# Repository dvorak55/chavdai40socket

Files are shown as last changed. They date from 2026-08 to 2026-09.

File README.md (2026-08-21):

# Chavdai40% Socket のご紹介
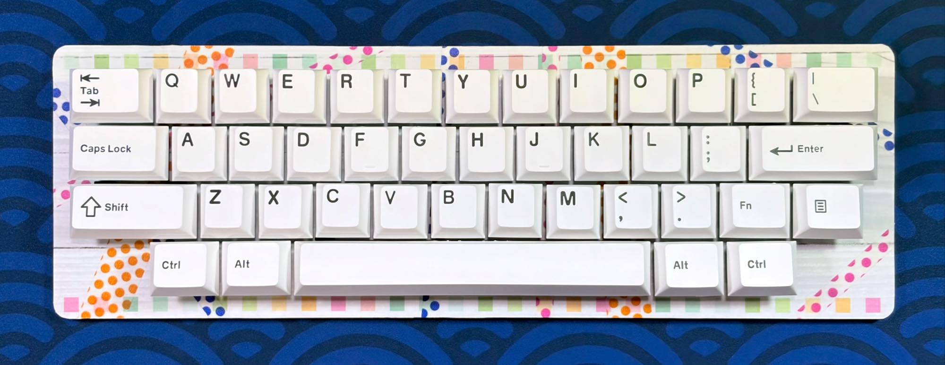
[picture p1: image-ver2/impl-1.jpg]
chavdai

 - Chavdai40%は、ちゃぶだいよんじゅっぱーせんと、と読みます
 - 古き良きちゃぶ台をイメージしました

### ロゴ
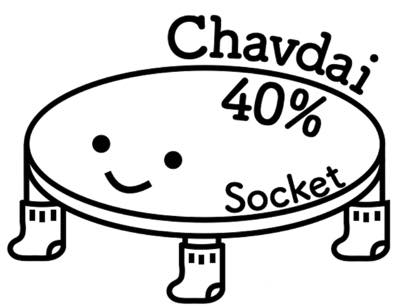
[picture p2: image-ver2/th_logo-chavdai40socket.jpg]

### 基板写真
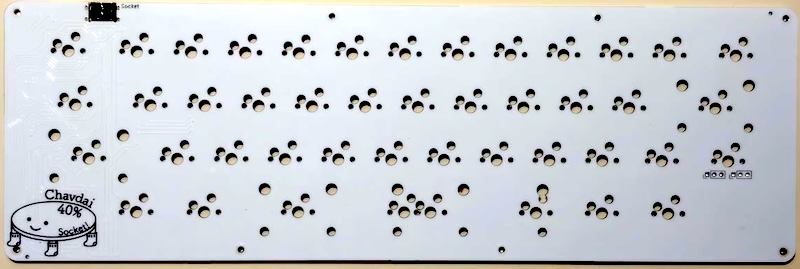
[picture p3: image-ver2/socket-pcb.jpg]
socket-pcb


## ★★★　詳細な組み立て説明はキットに同梱の説明書に記載しておりますので省略しますが、この場所では写真が掲載可能なので、デコレーション例や、組み立てで難しそうな点をご紹介いたします　★★★

## Chavdai40% Socket（ソケット）の特徴
 - デコレーションできる、コンパクトで健気なキーボード
    - 40％キーボードというサイズ感（キー数44、または42）
    - ソケット対応なので、とりあえず組み立てて後でデコレーションするのも可能です
    - キーボードケースが付属しているので、持ち運びしやすいです
 - リーズナブルなキーキャップが選べます
    - Amazonでも売っているキーキャップが使えます
    - ちょっと高価なキーキャップも、もちろん使えます
    - 日本語キーボードの縦長Enterキーは使えません
 - Vial（ヴァイアル）というソフトに対応しています
    - 40％キーボードでも数字と記号が入力できます
    - Ctrl＋a等の組み合わせを1つのキーに登録することも可能です
 - USB-Cでパソコン／スマホ／タブレットと接続して使えます

## Chavdai40%の組み立て例
### 組立例１（Chavdai40% Socket ＋ ダイソー リメイクシート ナチュラルウッド ホワイト ＋ mtマスキングテープ ドットシリーズ（オレンジ、ピンク、青） ＋ mtマスキングテープ幅3ｍｍシリーズ ＋ ダイソー マスキングテープ ＋ ダイソー デコレーションシール ＋ 一般的な白地に黒文字のキーキャップ）
なるべくリーズナブルにおしゃれなデザインを目標に、ダイソーの白い木目のリメイクシートを下地に、パステル調のマスキングテープでデコレーションしてみました。キーキャップは同じくリーズナブルに入手できる白地に黒文字のキーキャップを取り付けて、シンプルながらも明るい印象に仕上げました。  
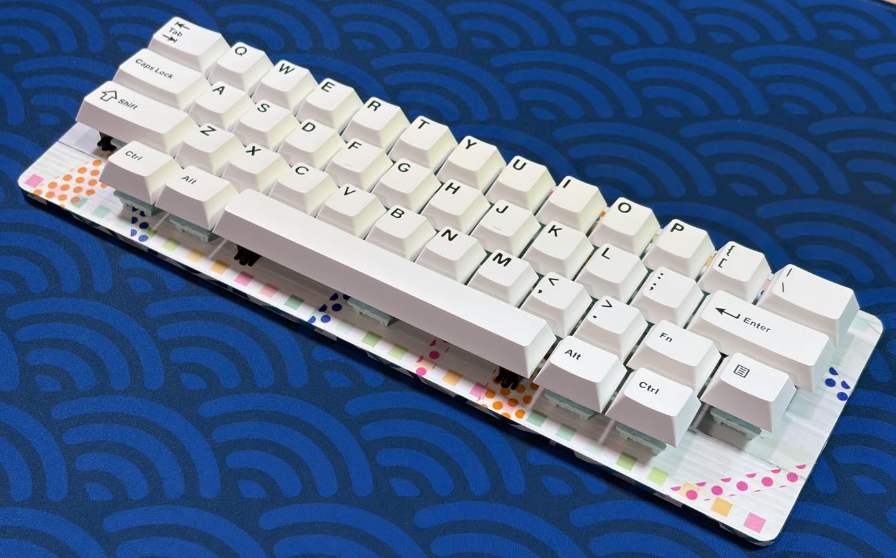
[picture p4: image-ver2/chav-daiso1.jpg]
chav-daiso1

マスキングテープをランダムに配置して、おしゃれな感じにしてみました。  
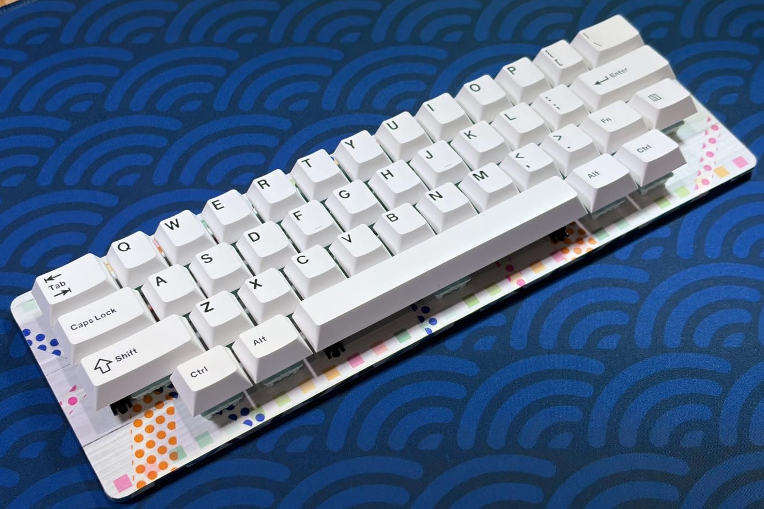
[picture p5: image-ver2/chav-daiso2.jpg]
chav-daiso2

リメイクシートとキーキャップセットは以下で購入可能です（2026年8月15日現在）  

●リメイクシート（ダイソー）  
[https://jp.daisonet.com/products/4900662759840)](https://jp.daisonet.com/products/4900662759840)  
●マスキングテープ（mtドット系）  
[https://shop.masking-tape.jp/products/list.php?category=99](https://shop.masking-tape.jp/products/list.php?category=99)  
●キーキャップ（Amazon.co.jp）  
[https://amzn.asia/d/0fVIauQW](https://amzn.asia/d/0fVIauQW)  

### 組立例２（Chavdai40% ＋ mtリメイクシートKapitza SUN ＋ Tai-Hao ABS Cubic Miami Surf）
※こちらはChavdai40％の以前のモデルでのデコレーション事例です。  
赤色の丸がかわいいリメイクシートと、ピンク色のキーキャップを組み合わせると、とってもポップな色合いになります。  
chav-taihao1
アクセントカラーの青色キーキャップが華を添えている感じですね。  
chav-taihao2
リメイクシートとキーキャップセットは現在は入手できません。  

### 組立例３（Chavdai40% ＋ mtリメイクシートKapitza FUJI ＋ GMK ECLIPSE）
※こちらはChavdai40％の以前のモデルでのデコレーション事例です。  
青色の三角がクールなリメイクシートと、青色黒色のキーキャップを組み合わせると、とっても引き締まった色合いになります。  
chav-eclipse1
GMKのキーキャップセットなので、スペースキーを分割できます。この写真ではスペースキーが打ちやすいように上下逆につけています。  
chav-eclipse2
リメイクシートとキーキャップセットは現在は入手できません。  

## デフォルトのキーマップ（JISの設定です）
### 44キーのキーマップ  
#### デフォルトレイヤー  
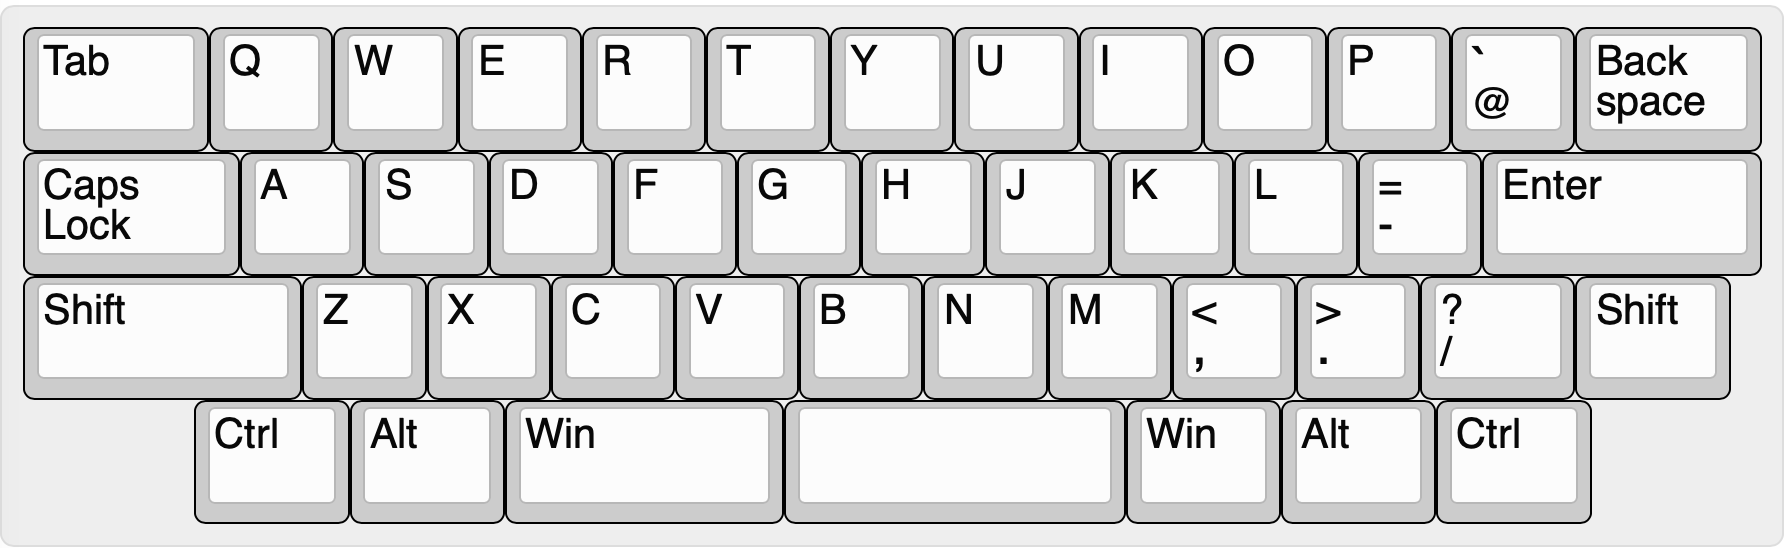
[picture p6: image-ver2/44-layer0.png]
44-layer0

#### レイヤー1  
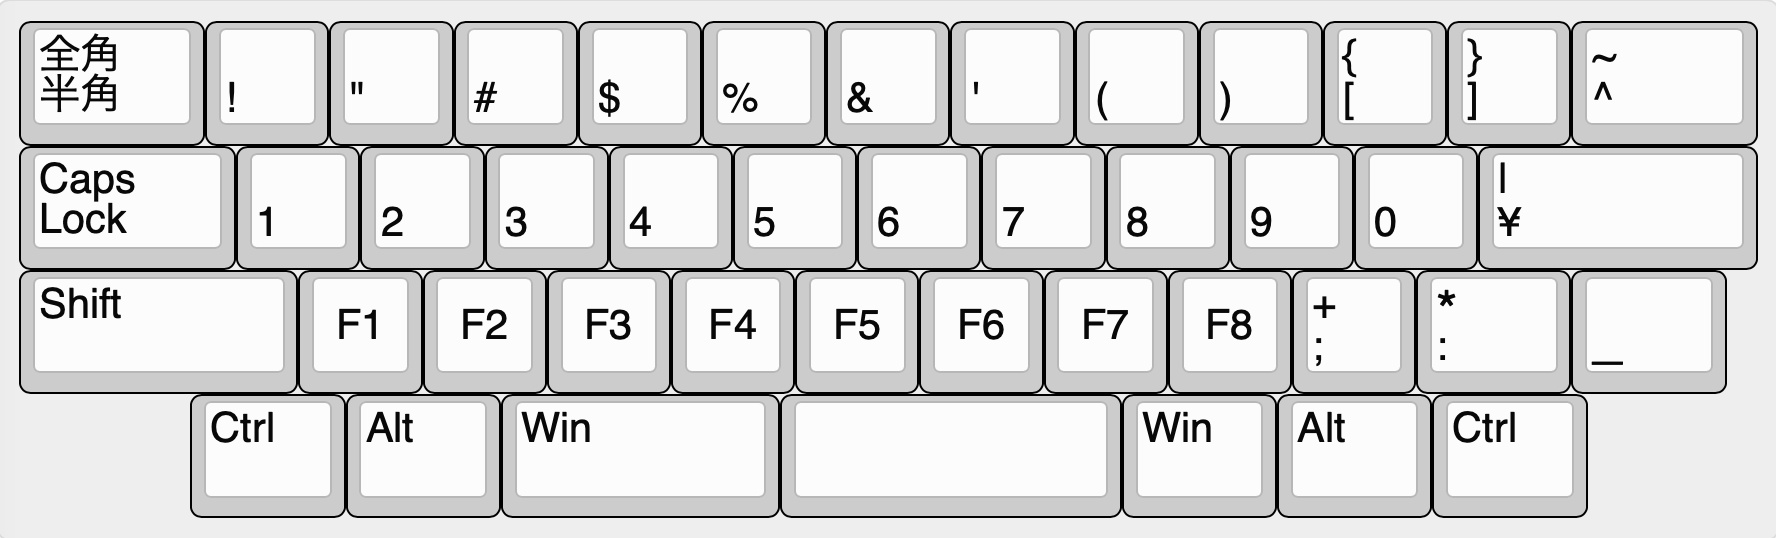
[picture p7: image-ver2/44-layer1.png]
44-layer1


### 42キーのキーマップ
#### デフォルトレイヤー  
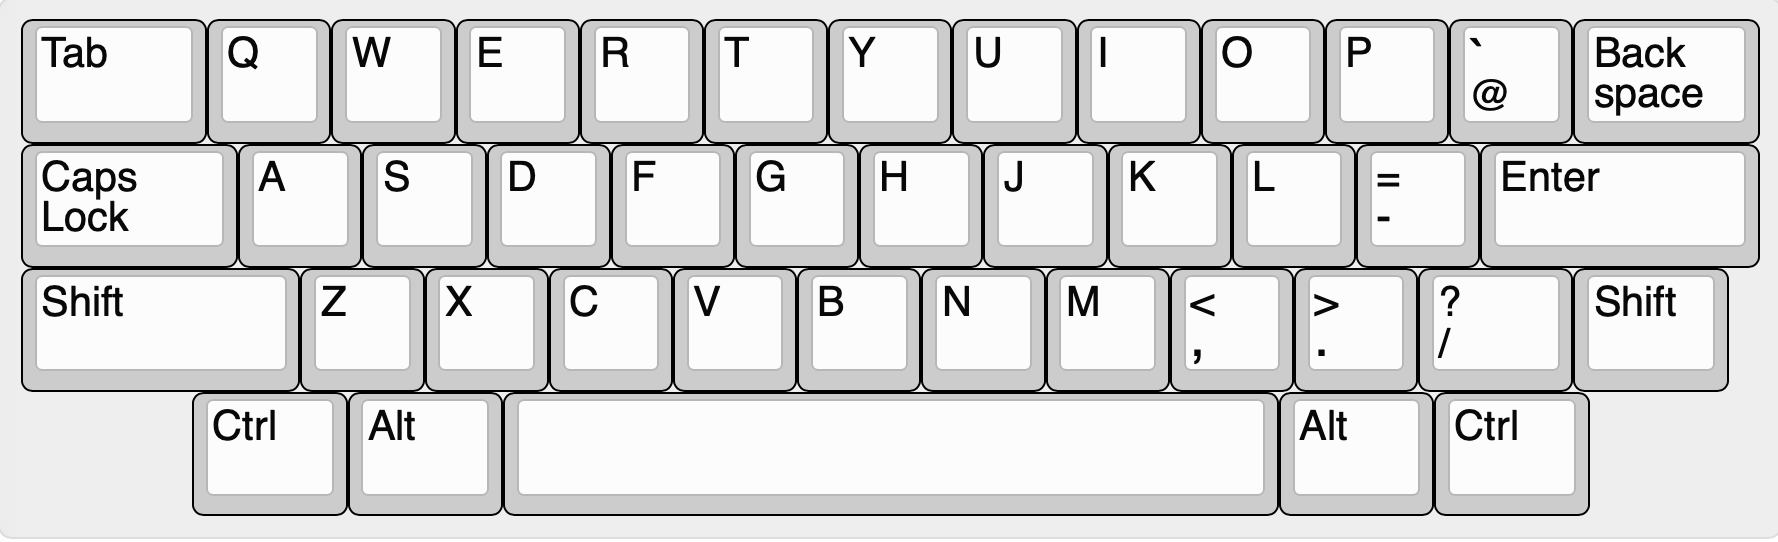
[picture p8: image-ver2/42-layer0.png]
42-layer0

#### レイヤー1  
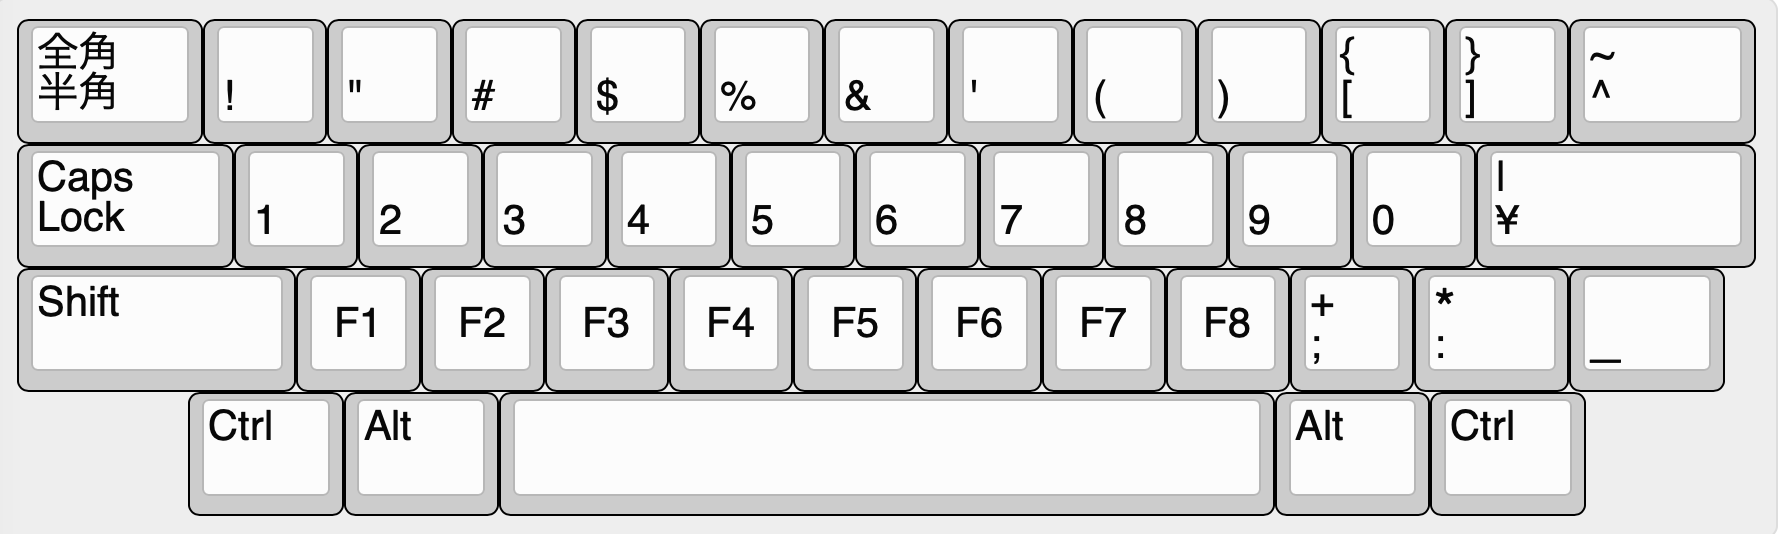
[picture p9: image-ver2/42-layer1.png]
42-layer1


### 日本語キーボードか、英字キーボードかについて
Chavdai40% Socketでは、キットに付属の説明書内で、最初のキーマップは日本語キーボードのJISの設定にしています。  
もし英字キーボードの設定にしたい場合は、Vialの画面で以下の箇所を設定してください。  
上のメニューから『Keyboard Layout』を選び、その中から一番上にある『QWERTY』をクリックして選択します。  
これで、日本語キーボードのJISから、英字キーボードになります。  
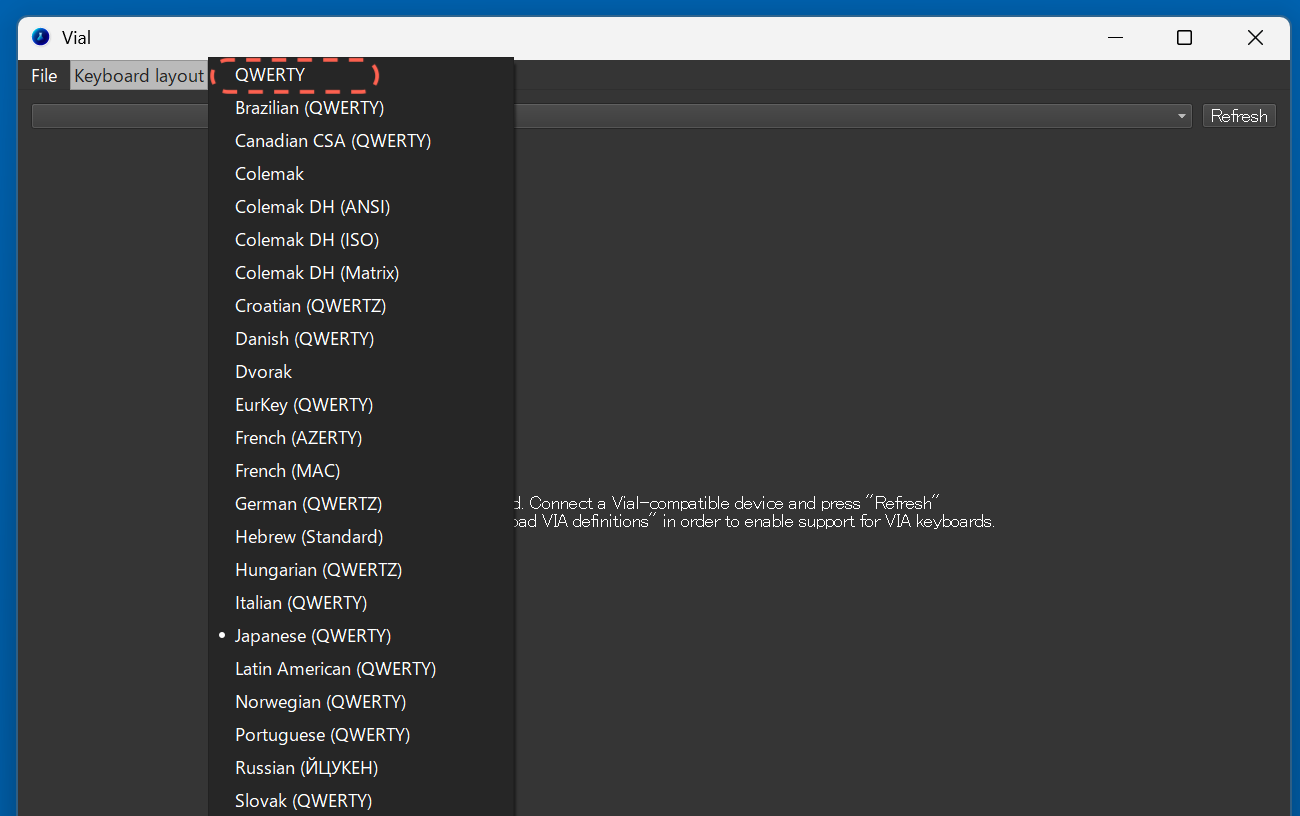
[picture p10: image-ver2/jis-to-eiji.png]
jis-to-eiji


## その他の問い合わせ先
X（twitter）: dombrick45 https://twitter.com/dombrick45  
※キットに同梱の説明書にメールアドレスが記載されております。

## 難しそうなポイント
### １．スタビライザーの取り付け
スタビライザーは、説明書にあるように大きな方の穴に爪を引っ掛けた後、小さい方の穴にもう片方の爪を嵌める手順で取り付けます。  
このスタビライザーを取り付けた後、キースイッチ・キーキャップを付けると、キースイッチがうまく戻らないことがあります。  
その場合は、キーキャップをつまんで、上下左右に動かしてみて下さい。 　
少し遊びができると、キースイッチがうまく戻るようになります。  
### ２．デコレーションの後に、キースイッチ・スタビライザーを取り付ける
おもて面にデコレーションのシール・シートを貼ると、キースイッチ・スタビライザーを取り付ける時、少しキツくなります。  
簡単にするため、キースイッチ・スタビライザーの取り付け箇所のシール・シートに、あらかじめ鉛筆やボールペンで穴を空けておくと良いです。
また、デコレーションを3枚ほど重ねた箇所のスイッチ取り付けはかなり辛いので、その場合は、スイッチの穴の箇所だけデコレーションを破いて取り除くと良いです。
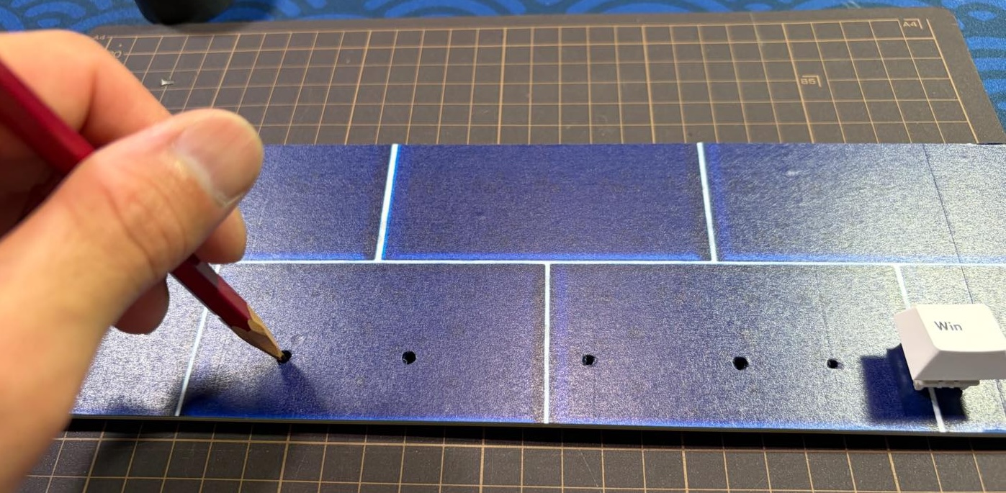
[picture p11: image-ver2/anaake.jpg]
anaake


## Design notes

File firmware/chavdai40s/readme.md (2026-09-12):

# Chavdai40 Socket  

chavdai40s

Chavdai40 Socket is very simple decoratable 40% keyboard

* Keyboard Maintainer: [t-miyajima](https://github.com/dvorak55)
* Hardware Supported: Chavdai40s PCB socket version.
* Hardware Availability: [yushakobo](https://shop.yushakobo.jp/collections/regular-keyboards/products/18395)

Make example for this keyboard (after setting up your build environment):

    make chavdai40s/rev1:vial  
    make chavdai40s/rev2:vial  

Flashing example for this keyboard:

    make chavdai40s/rev1:vial:flash  
    make chavdai40s/rev2:vial:flash  

See the [build environment setup](https://docs.qmk.fm/#/getting_started_build_tools) and the [make instructions](https://docs.qmk.fm/#/getting_started_make_guide) for more information. Brand new to QMK? Start with our [Complete Newbs Guide](https://docs.qmk.fm/#/newbs).

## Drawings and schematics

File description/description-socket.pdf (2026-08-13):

# 親しみやすい40%キーボード

## はんだ付けはソケットだけ

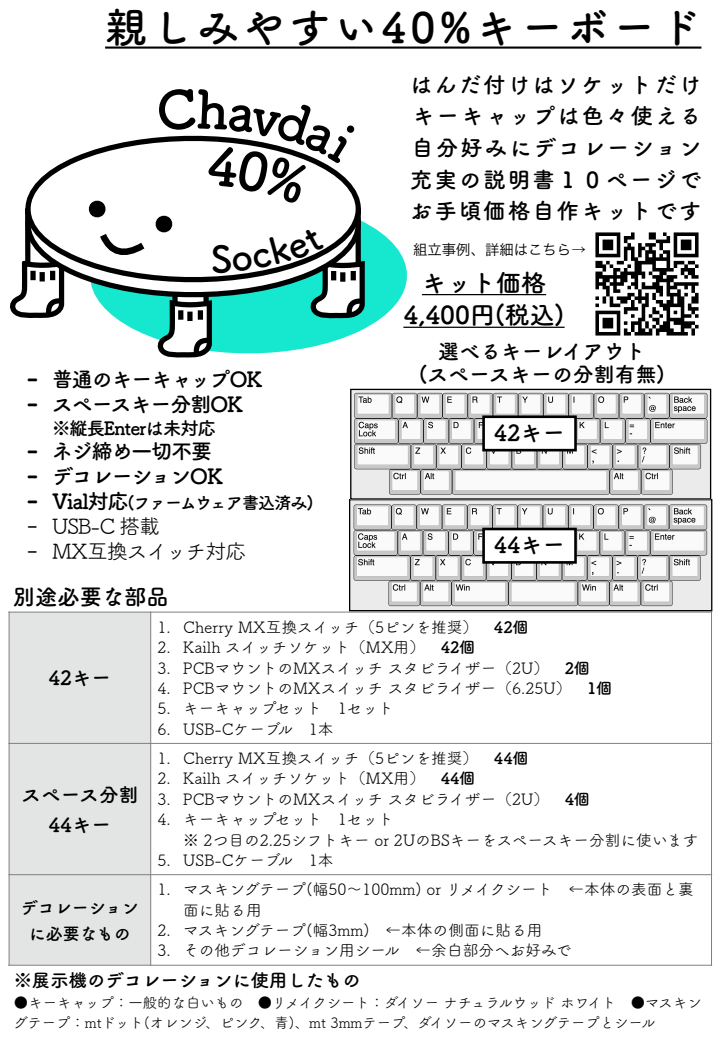
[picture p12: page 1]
Chavdai 40%; S et ock; キーキャップは色々使える 自分好みにデコレーション 充実の説明書１０ページで お手頃価格自作キットです; 別途必要な部品; - 普通のキーキャップOK - スペースキー分割OK; ※縦長Enterは未対応 - ネジ締め一切不要 - デコレーションOK - Vial対応(ファームウェア書込済み) - USB-C 搭載 - MX互換スイッチ対応; キット価格 4,400円(税込); 選べるキーレイアウト (スペースキーの分割有無); 組立事例、詳細はこちら→

42キー | 1. Cherry MX互換スイッチ（5ピンを推奨）　42個 2. Kailh スイッチソケット（MX用）　42個 3. PCBマウントのMXスイッチ スタビライザー（2U）　2個 4. PCBマウントのMXスイッチ スタビライザー（6.25U）　1個 5. キーキャップセット　1セット 6. USB-Cケーブル　1本

スペース分割 44キー | 1. Cherry MX互換スイッチ（5ピンを推奨）　44個 2. Kailh スイッチソケット（MX用）　44個 3. PCBマウントのMXスイッチ スタビライザー（2U）　4個 4. キーキャップセット　1セット ※ 2つ目の2.25シフトキー or 2UのBSキーをスペースキー分割に使います 5. USB-Cケーブル　1本

デコレーション に必要なもの | 1. マスキングテープ(幅50～100mm) or リメイクシート　←本体の表面と裏 面に貼る用 2. マスキングテープ(幅3mm)　←本体の側面に貼る用 3. その他デコレーション用シール　←余白部分へお好みで

※展示機のデコレーションに使用したもの
●キーキャップ：一般的な白いもの　●リメイクシート：ダイソー ナチュラルウッド ホワイト　●マスキン
グテープ：mtドット(オレンジ、ピンク、青)、mt 3mmテープ、ダイソーのマスキングテープとシール

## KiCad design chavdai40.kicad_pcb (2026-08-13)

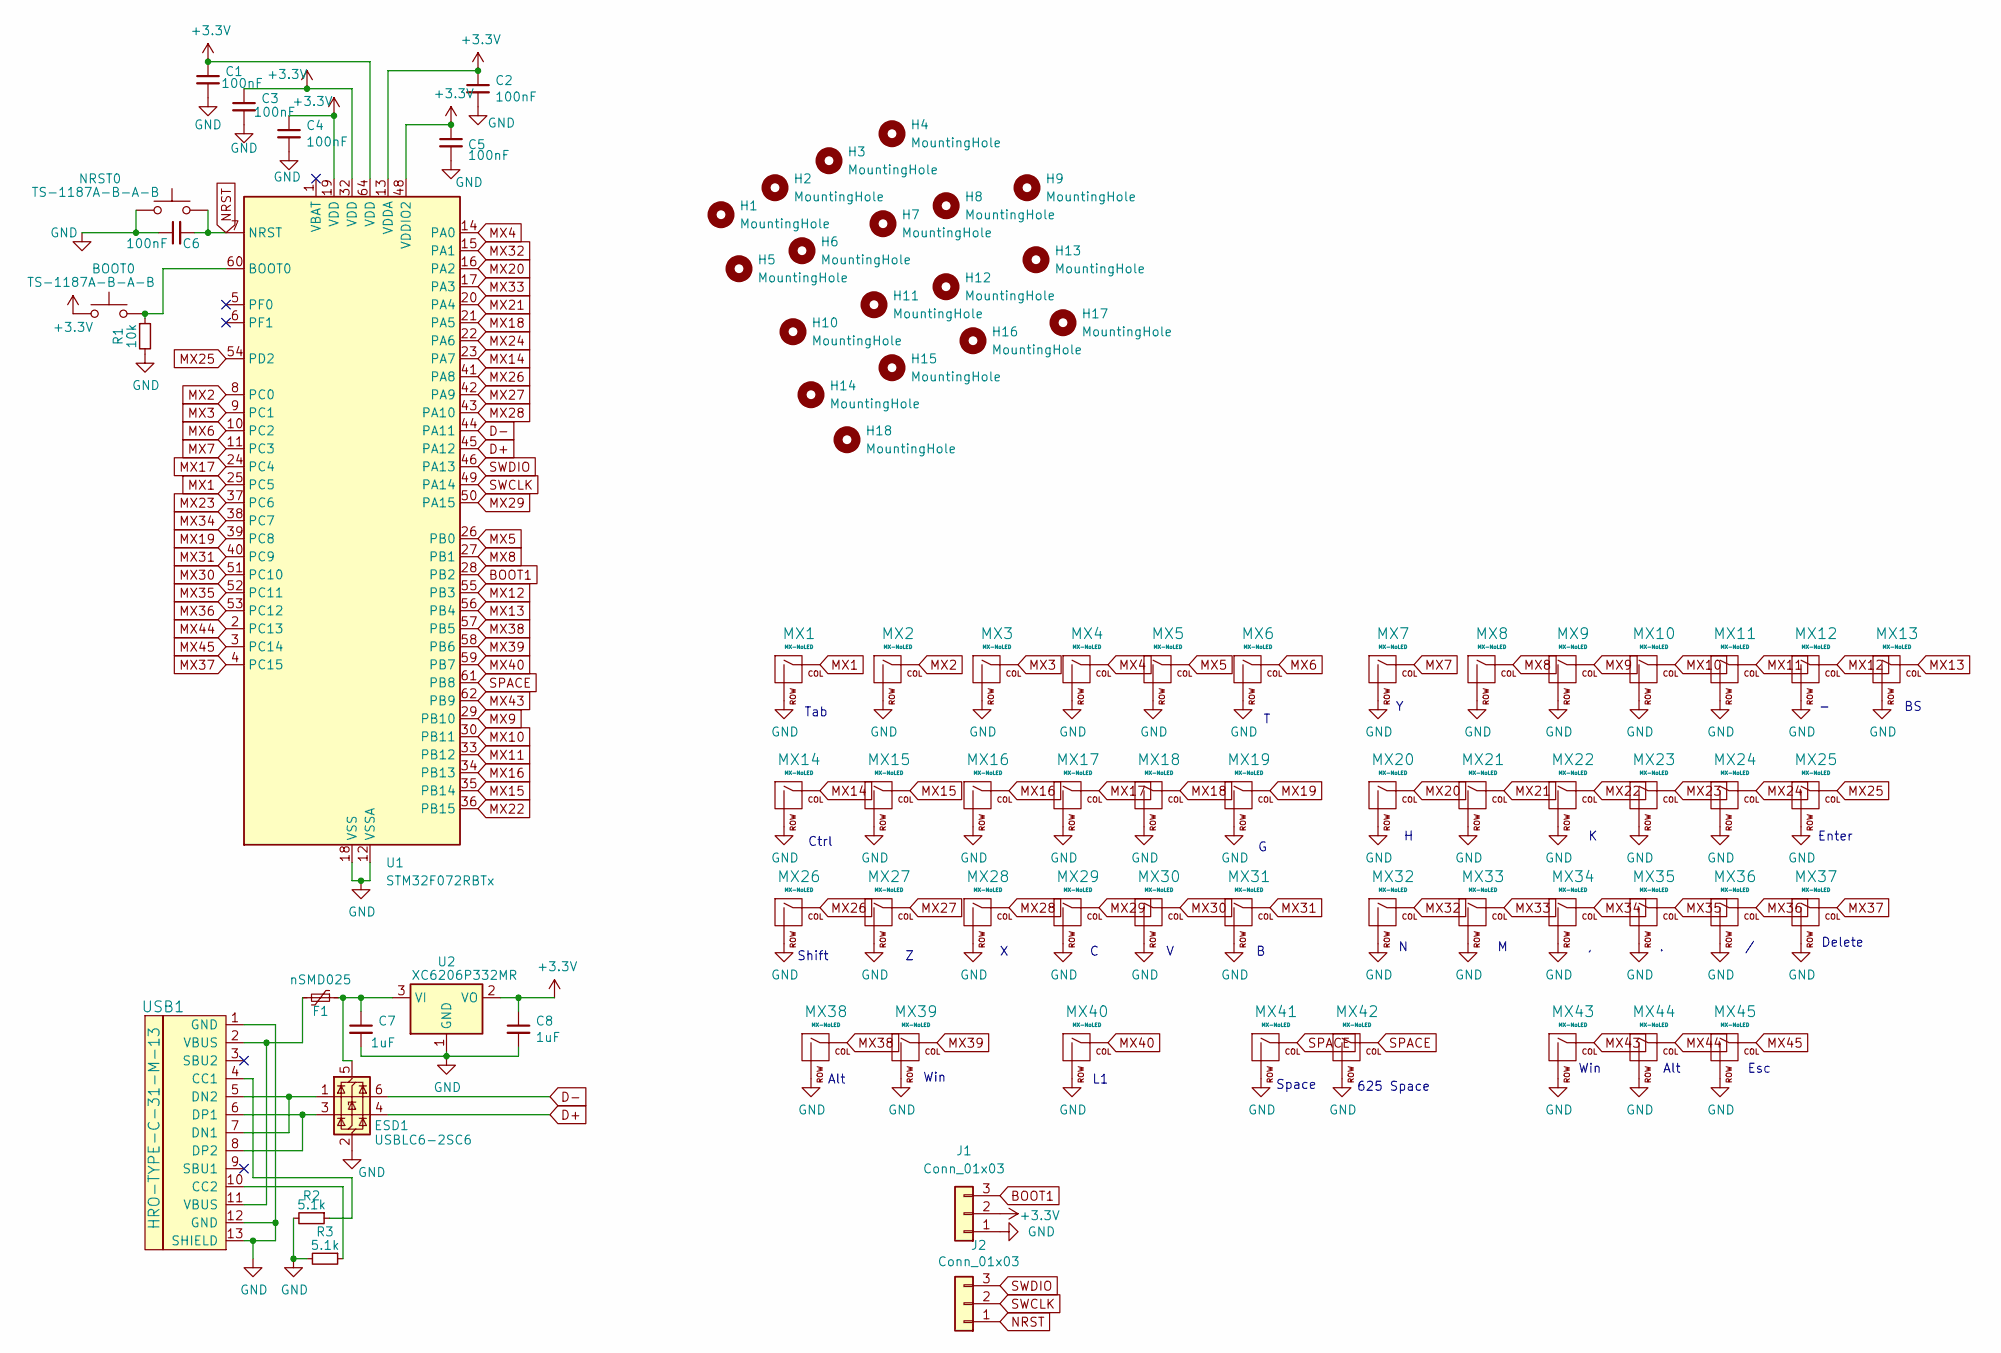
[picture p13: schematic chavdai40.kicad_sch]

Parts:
BOOT0: TS-1187A-B-A-B; SKQGADE010
C1, C2, C3, C4, C5, C6: 100nF; C_0402_1005Metric
C7, C8: 1uF; C_0603_1608Metric
ESD1: USBLC6-2SC6; SOT-23-6
F1: nSMD025; Fuse_1206_3216Metric
H1, H2, H11, H12, H13, H14, H15, H16, H17, H18: MountingHole; TestPoint_Pad_D4.0mm
H3, H4, H5, H6, H7, H8, H9, H10: MountingHole; TestPoint_THTPad_D4.0mm_Drill2.0mm
J1, J2: Conn_01x03; PinHeader_1x03_P2.54mm_Vertical
MX1, MX13: MX-NoLED; MXOnly-1.5U-Hotswap
MX2, MX3, MX4, MX5, MX6, MX7, MX8, MX9, MX10, MX11, MX12, MX15, MX16, MX17, MX18, MX19, MX20, MX21, MX22, MX23, MX24, MX27, MX28, MX29, MX30, MX31, MX32, MX33, MX34, MX35: MX-NoLED; MXOnly-1U-Hotswap
MX14: MX-NoLED; MXOnly-1.75U-Hotswap
MX25, MX26, MX40: MX-NoLED; MXOnly-2.25U-Hotswap-ReversedStabilizers
MX36, MX37, MX38, MX39, MX43, MX44, MX45: MX-NoLED; MXOnly-1.25U-Hotswap
MX41: MX-NoLED; MXOnly-2.75U-Hotswap-ReversedStabilizers
MX42: MX-NoLED; MXOnly-6.25U-Hotswap-ReversedStabilizers
NRST0: TS-1187A-B-A-B; SKQGADE010
R1: 10k; R_0603_1608Metric
R2, R3: 5.1k; R_0603_1608Metric
U1: STM32F072RBTx; LQFP-64_10x10mm_P0.5mm
U2: XC6206P332MR; TSOT-23
USB1: HRO-TYPE-C-31-M-13

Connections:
+3.3V: BOOT0.1, C1.1, C2.1, C3.1, C4.1, C5.1, C8.1, J1.2, U1.13 (VDDA), U1.19 (VDD), U1.32 (VDD), U1.48 (VDDIO2), U1.64 (VDD), U2.2 (VO)
BOOT1: J1.3, U1.28 (PB2)
D+: ESD1.4 (I/O2), U1.45 (PA12)
D-: ESD1.6 (I/O1), U1.44 (PA11)
GND: C1.2, C2.2, C3.2, C4.2, C5.2, C6.1, C7.2, C8.2, ESD1.2 (GND), J1.1, MX1.2 (ROW), MX2.2 (ROW), MX3.2 (ROW), MX4.2 (ROW), MX5.2 (ROW), MX6.2 (ROW), MX7.2 (ROW), MX8.2 (ROW), MX9.2 (ROW), MX10.2 (ROW), MX11.2 (ROW), MX12.2 (ROW), MX13.2 (ROW), MX14.2 (ROW), MX15.2 (ROW), MX16.2 (ROW), MX17.2 (ROW), MX18.2 (ROW), MX19.2 (ROW), MX20.2 (ROW), MX21.2 (ROW), MX22.2 (ROW), MX23.2 (ROW), MX24.2 (ROW), MX25.2 (ROW), MX26.2 (ROW), MX27.2 (ROW), MX28.2 (ROW), MX29.2 (ROW), MX30.2 (ROW), MX31.2 (ROW), MX32.2 (ROW), MX33.2 (ROW), MX34.2 (ROW), MX35.2 (ROW), MX36.2 (ROW), MX37.2 (ROW), MX38.2 (ROW), MX39.2 (ROW), MX40.2 (ROW), MX41.2 (ROW), MX42.2 (ROW), MX43.2 (ROW), MX44.2 (ROW), MX45.2 (ROW), NRST0.1, R1.2, R2.2, R3.2, U1.12 (VSSA), U1.18 (VSS), U1.31 (VSS), U1.47 (VSS), U1.63 (VSS), U2.1 (GND), USB1.1 (GND), USB1.12 (GND), USB1.13 (SHIELD)
MX1: MX1.1 (COL), U1.25 (PC5)
MX2: MX2.1 (COL), U1.8 (PC0)
MX3: MX3.1 (COL), U1.9 (PC1)
MX4: MX4.1 (COL), U1.14 (PA0)
MX5: MX5.1 (COL), U1.26 (PB0)
MX6: MX6.1 (COL), U1.10 (PC2)
MX7: MX7.1 (COL), U1.11 (PC3)
MX8: MX8.1 (COL), U1.27 (PB1)
MX9: MX9.1 (COL), U1.29 (PB10)
MX10: MX10.1 (COL), U1.30 (PB11)
MX11: MX11.1 (COL), U1.33 (PB12)
MX12: MX12.1 (COL), U1.55 (PB3)
MX13: MX13.1 (COL), U1.56 (PB4)
MX14: MX14.1 (COL), U1.23 (PA7)
MX15: MX15.1 (COL), U1.35 (PB14)
MX16: MX16.1 (COL), U1.34 (PB13)
MX17: MX17.1 (COL), U1.24 (PC4)
MX18: MX18.1 (COL), U1.21 (PA5)
MX19: MX19.1 (COL), U1.39 (PC8)
MX20: MX20.1 (COL), U1.16 (PA2)
MX21: MX21.1 (COL), U1.20 (PA4)
MX22: MX22.1 (COL), U1.36 (PB15)
MX23: MX23.1 (COL), U1.37 (PC6)
MX24: MX24.1 (COL), U1.22 (PA6)
MX25: MX25.1 (COL), U1.54 (PD2)
MX26: MX26.1 (COL), U1.41 (PA8)
MX27: MX27.1 (COL), U1.42 (PA9)
MX28: MX28.1 (COL), U1.43 (PA10)
MX29: MX29.1 (COL), U1.50 (PA15)
MX30: MX30.1 (COL), U1.51 (PC10)
MX31: MX31.1 (COL), U1.40 (PC9)
MX32: MX32.1 (COL), U1.15 (PA1)
MX33: MX33.1 (COL), U1.17 (PA3)
MX34: MX34.1 (COL), U1.38 (PC7)
MX35: MX35.1 (COL), U1.52 (PC11)
MX36: MX36.1 (COL), U1.53 (PC12)
MX37: MX37.1 (COL), U1.4 (PC15)
MX38: MX38.1 (COL), U1.57 (PB5)
MX39: MX39.1 (COL), U1.58 (PB6)
MX40: MX40.1 (COL), U1.59 (PB7)
MX43: MX43.1 (COL), U1.62 (PB9)
MX44: MX44.1 (COL), U1.2 (PC13)
MX45: MX45.1 (COL), U1.3 (PC14)
NRST: C6.2, J2.1, NRST0.2, U1.7 (NRST)
unnamed: C7.1, ESD1.5 (VBUS), F1.1, U2.3 (VI)
unnamed: F1.2, USB1.2 (VBUS), USB1.11 (VBUS)
unnamed: BOOT0.2, R1.1, U1.60 (BOOT0)
unnamed: R2.1, USB1.4 (CC1)
unnamed: R3.1, USB1.10 (CC2)
unnamed: ESD1.1 (I/O1), USB1.5 (DN2), USB1.7 (DN1)
unnamed: ESD1.3 (I/O2), USB1.6 (DP1), USB1.8 (DP2)
SPACE: MX41.1 (COL), MX42.1 (COL), U1.61 (PB8)
SWCLK: J2.2, U1.49 (PA14)
SWDIO: J2.3, U1.46 (PA13)

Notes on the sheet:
Win
Space
Enter
Delete
Esc
625 Space
Tab
Alt
Ctrl
Shift

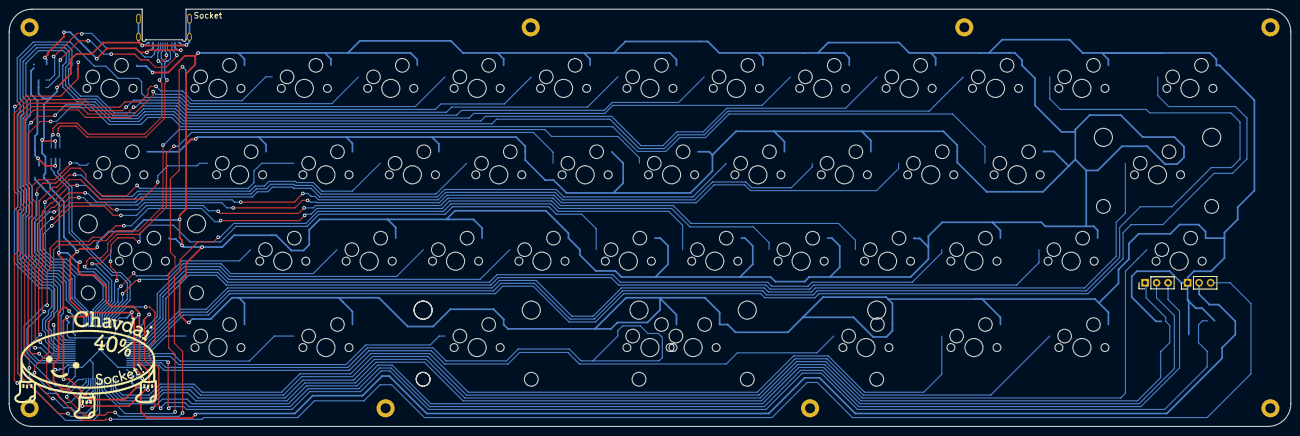
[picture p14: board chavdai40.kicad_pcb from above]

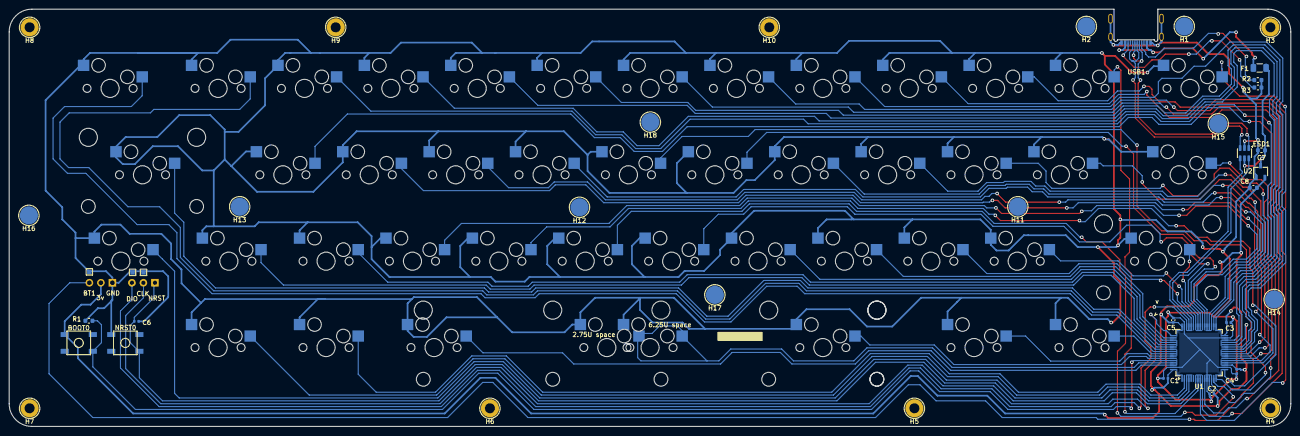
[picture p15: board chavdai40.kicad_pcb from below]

Board: 2 copper layers, 282.6 x 92.0 mm, 83 parts (36 on the bottom side), 59 nets.

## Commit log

2026-08-13 uploadr chavdai40 Socket pcb and firmware files
    [chavdai40-bp.kicad_pcb, chavdai40-bp.kicad_sch, chavdai40.kicad_pcb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]
2026-08-13 Update README.md socket
2026-08-21 change pcb image
